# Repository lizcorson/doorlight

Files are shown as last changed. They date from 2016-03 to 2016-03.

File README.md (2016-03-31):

# doorlight
Opening your front door will turn on a strip of LEDs inside. Never walk into a dark house at night! Plus, the strip lights up red so as not to affect your eyes' adjustment to the dark.

## Status
Complete!

## Parts Used
- Pro Mini clone http://www.aliexpress.com/item/Pro-Mini-Module-Atmega328-5V-16M-For-Arduino-Compatible-With-Nano/2021666535.html
- LED strip http://www.aliexpress.com/item/1m-4m-5m-WS2812B-Smart-led-pixel-strip-Black-White-PCB-30-60-144-leds-m/32483042485.html
- Magnetic Door Switch https://www.sparkfun.com/products/13247
- 1000 μF capacitor
- 330 Ω resistor
- DC power jack https://www.sparkfun.com/products/10785
- 5V 2A power supply https://www.sparkfun.com/products/12889
- Circuit board http://smile.amazon.com/gp/product/B00PKVSQX2
- Cast acrylic, 3/16" http://www.mcmaster.com/#8505K82 - in the future, I'd use thinner acrylic.
- Command medium cord clips http://smile.amazon.com/dp/B0084M696A
- Command medium picture hanging strips http://smile.amazon.com/dp/B000M3YGOQ
- 3M mounting tape http://smile.amazon.com/dp/B00004Z4A8

## Build it yourself!

1. Upload the doorlight sketch to your Arduino-compatible board.
2. Solder the circuit shown in the circuit diagram.
3. Make a case. I laser cut mine from acrylic. The laser cutter plans are in the case folder.
4. Attach the command cord clips above your door.
5. Position everything as appropriate for your door and your wiring.
6. Mount the control box case to the wall with command strips.
7. Mount the door sensor to the door. Be sure to put the side with wires on the wall.
8. Slide the LED strip into the command cord clips. Secure the strip to to the clips using mounting tape.
9. Plug everything in, and you're good to go!

## Libraries
FastLED https://github.com/FastLED/FastLED

## Final Build Photos
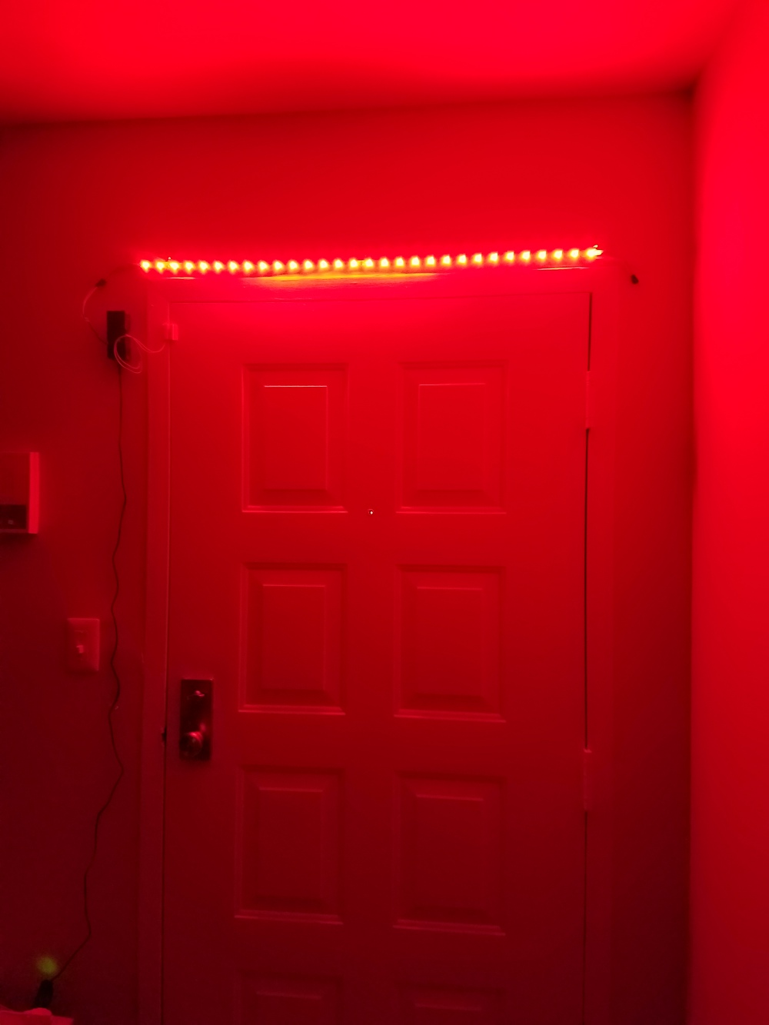
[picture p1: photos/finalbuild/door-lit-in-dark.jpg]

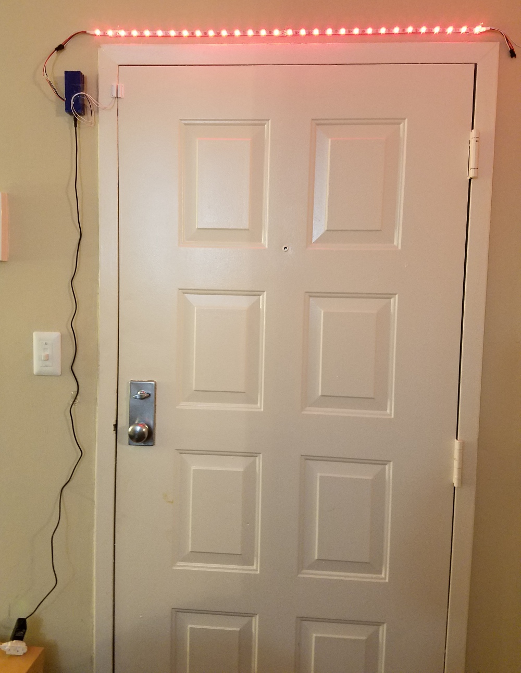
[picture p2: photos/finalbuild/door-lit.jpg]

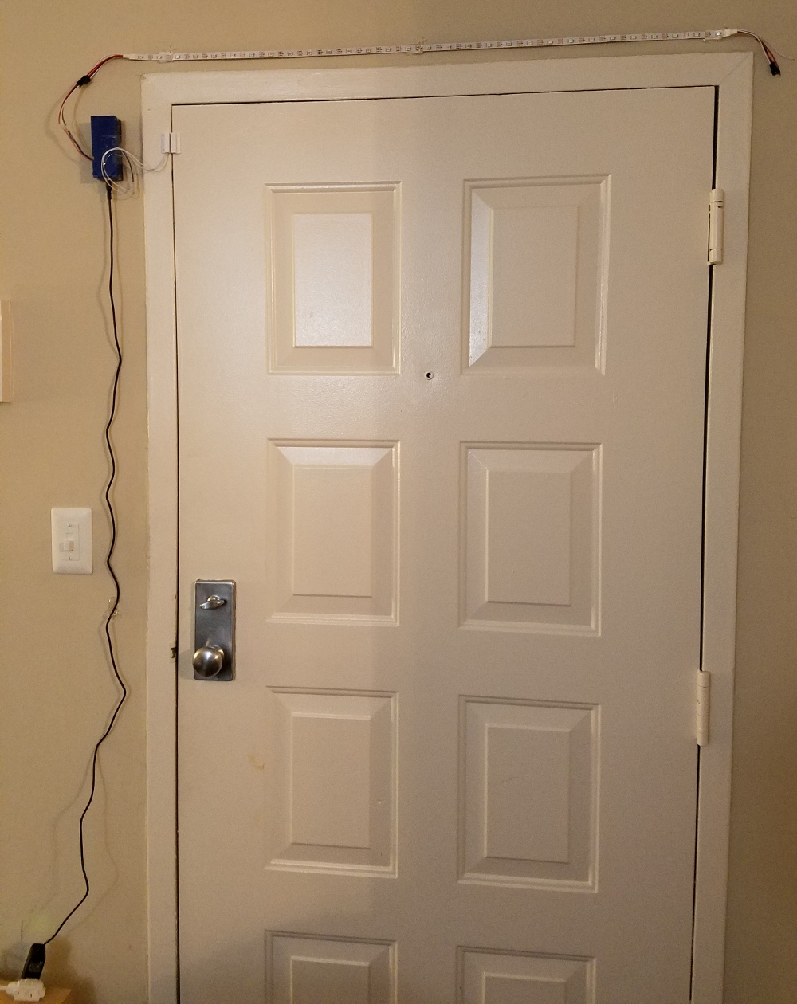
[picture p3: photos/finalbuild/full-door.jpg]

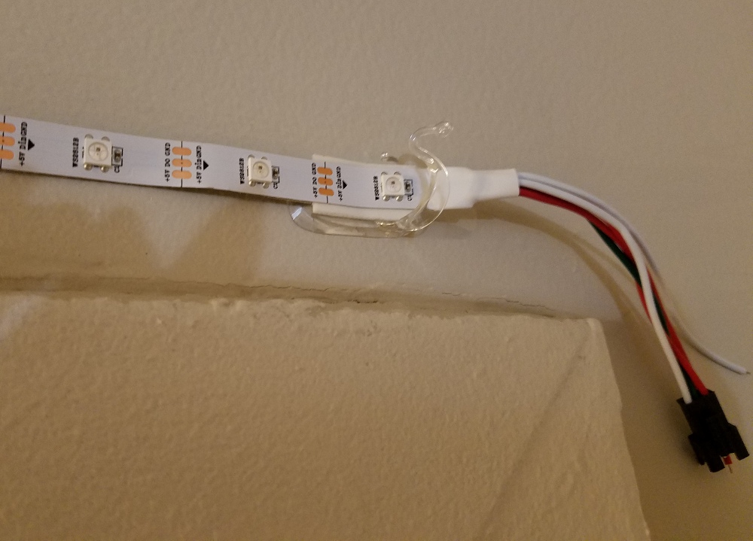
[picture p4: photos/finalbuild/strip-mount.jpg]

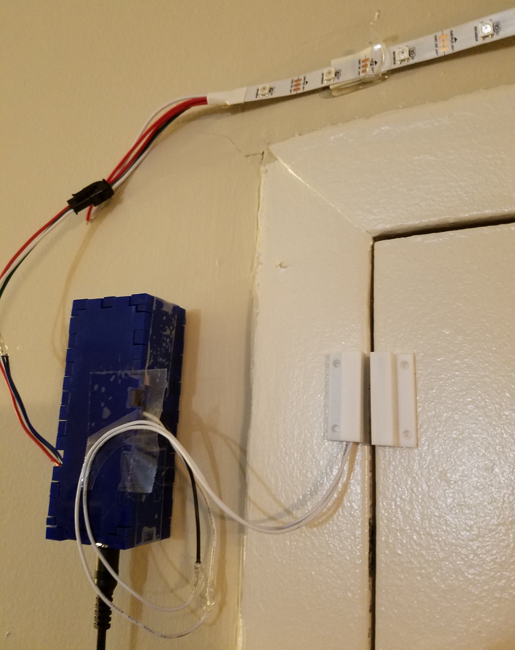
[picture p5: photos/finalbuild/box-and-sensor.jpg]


## Progress Shots
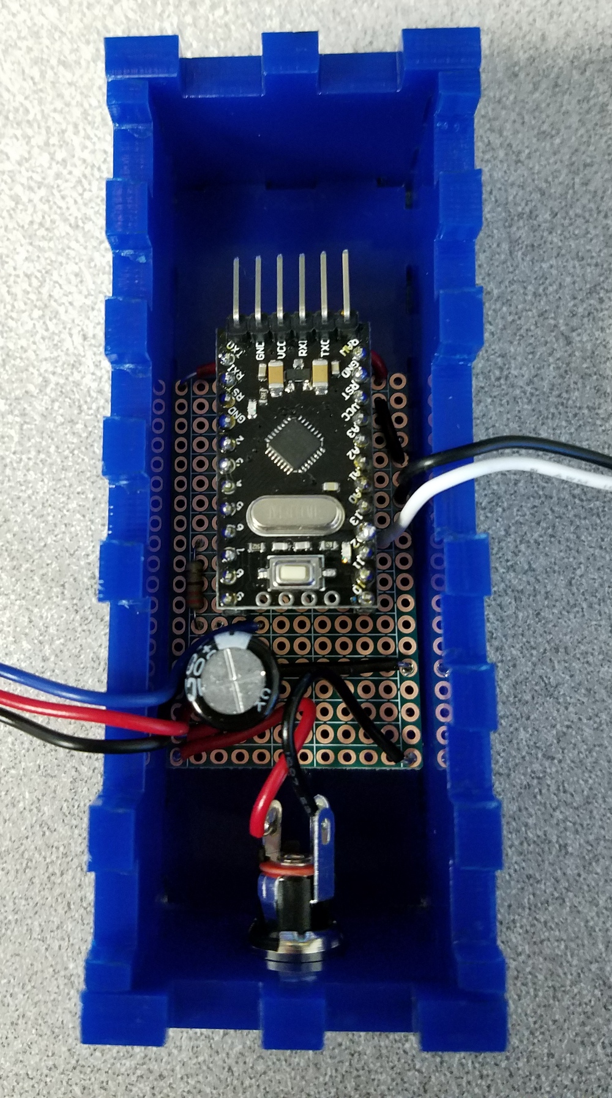
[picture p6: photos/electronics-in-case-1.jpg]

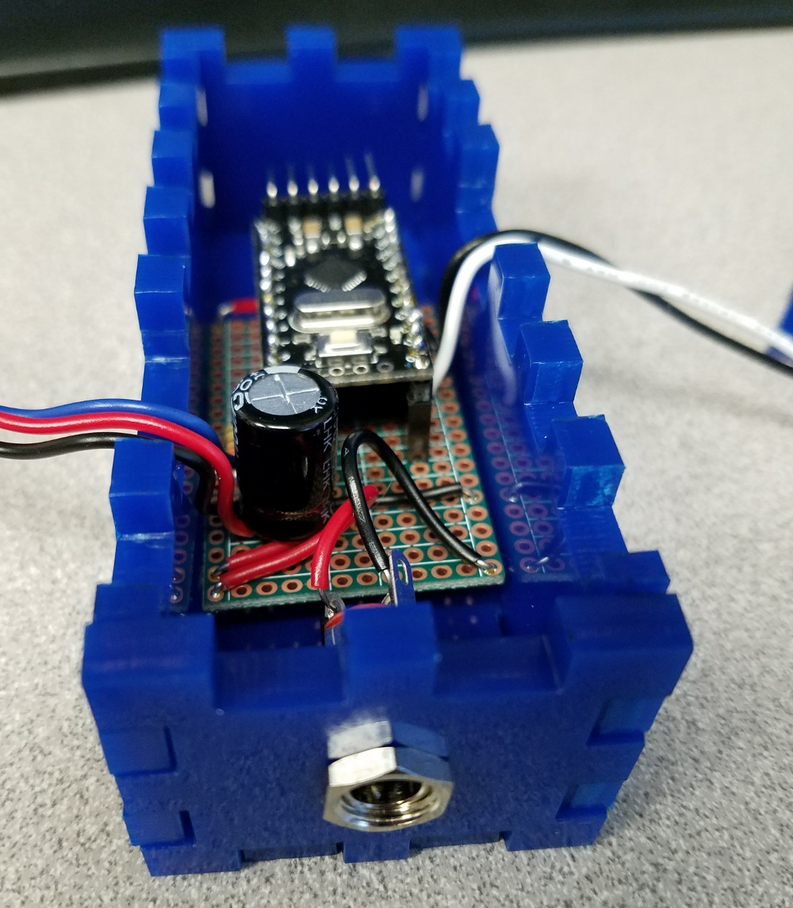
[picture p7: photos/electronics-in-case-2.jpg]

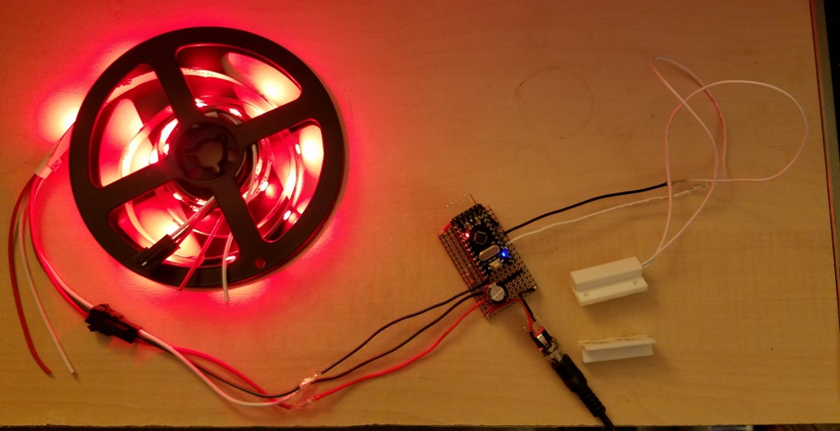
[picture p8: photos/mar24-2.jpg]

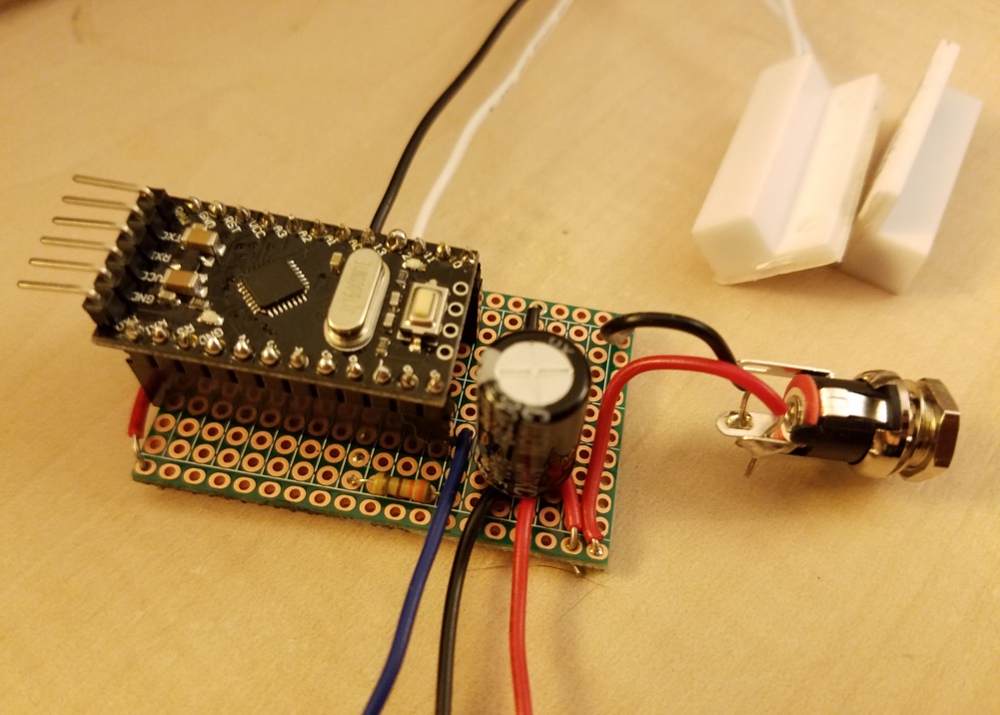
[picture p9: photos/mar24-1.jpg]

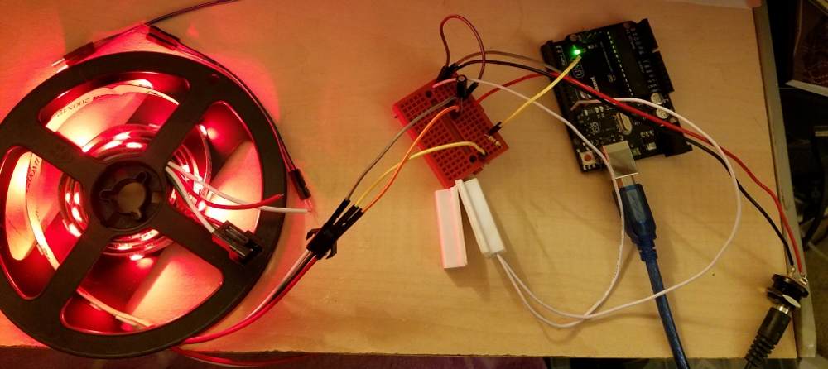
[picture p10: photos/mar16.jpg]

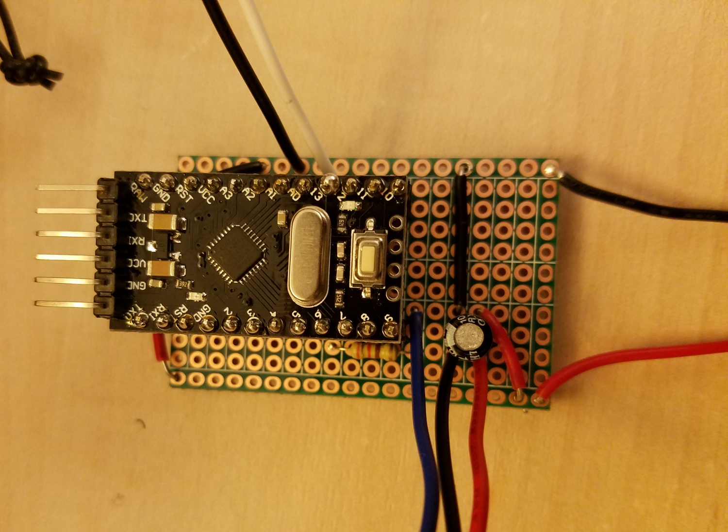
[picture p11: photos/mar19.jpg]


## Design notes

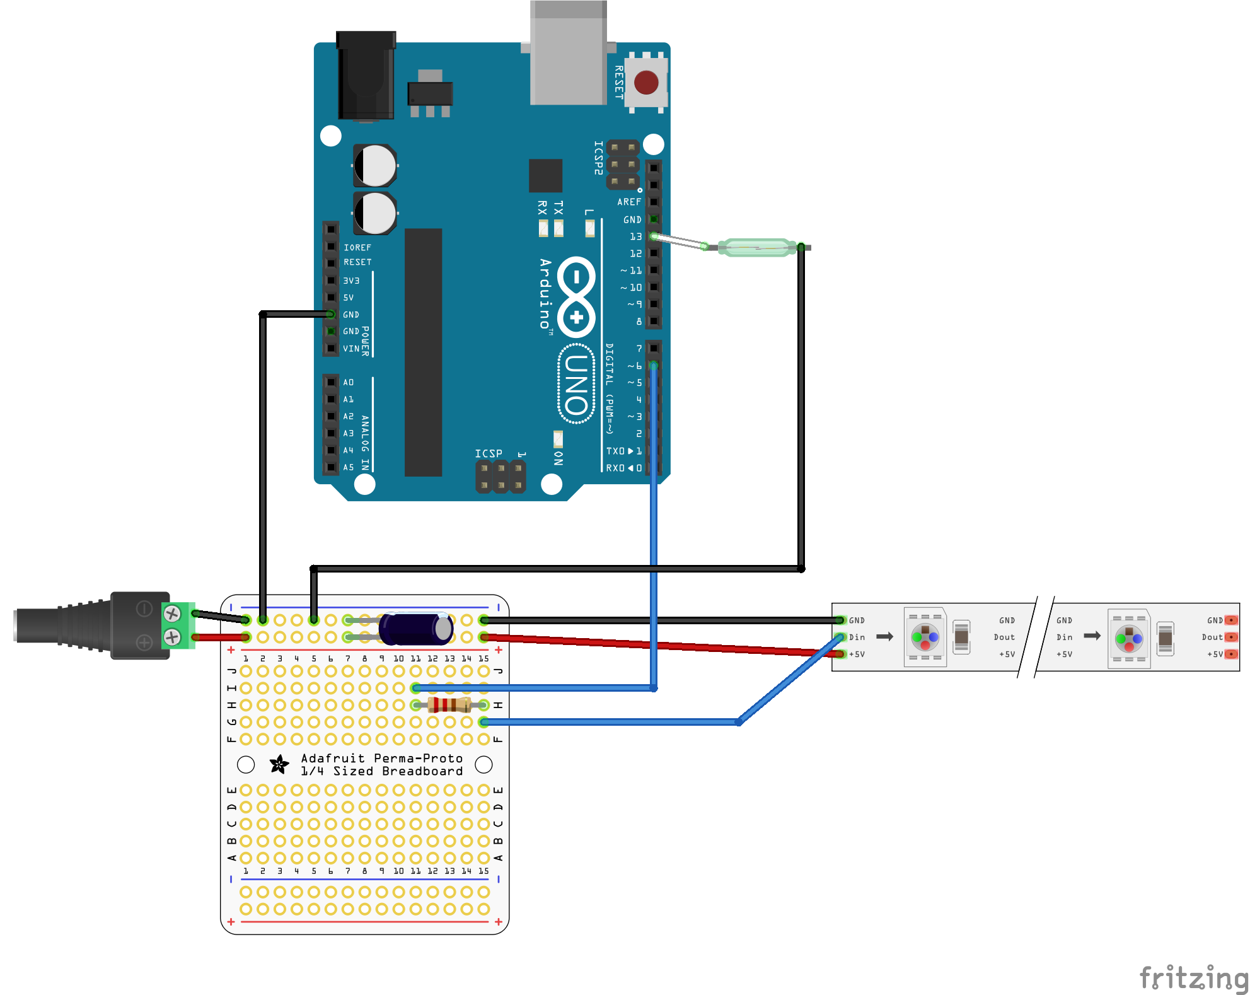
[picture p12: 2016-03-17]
circuitdiagram/doorlight.png

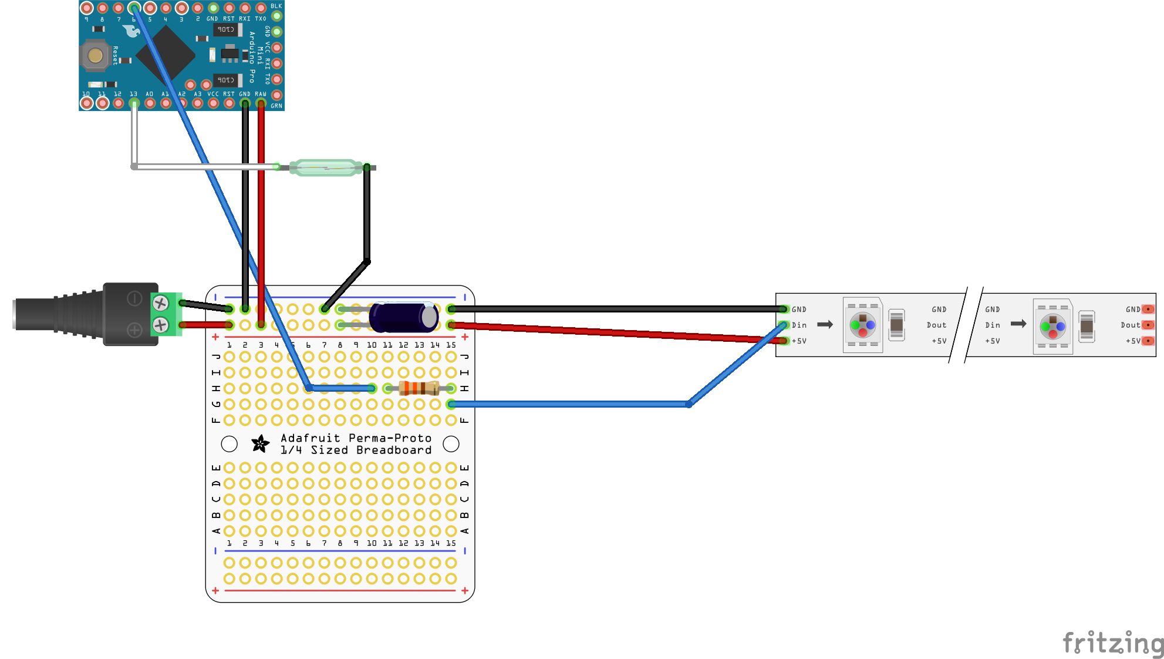
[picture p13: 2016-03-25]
circuitdiagram/doorlight pro mini.png

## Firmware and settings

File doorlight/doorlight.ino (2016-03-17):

/* doorlight
 * Turns an LED strip on when a magnetic door sensor is triggered by a door opening.
 * Turns off after 60 seconds.
 * Thanks to this tutorial: https://learn.adafruit.com/using-ifttt-with-adafruit-io/overview
 * 
 * Liz Corson
 * 16 March 2016
 */

#include "FastLED.h"

#define DOOR 13 // door sensor is on pin 13
#define NUM_LEDS 30
#define DATA_PIN 6 // LED strip on pin 6

const int doorCheckDelay = 500;
long lastDoorCheck = 0;
long lightsOnWait = 60000; //60 seconds
long lightsOnTime = 0;
byte lightsOn = 0;

// Define the array of leds
CRGB leds[NUM_LEDS];

void setup() { 
  	  FastLED.addLeds<NEOPIXEL, DATA_PIN>(leds, NUM_LEDS);
      pinMode(DOOR, INPUT_PULLUP);
      Serial.begin(9600);
      LEDsOff();
}

void loop() { 
  if ((unsigned long)(millis() - lastDoorCheck) > doorCheckDelay) {
    // if door isn't open, we don't need to send anything
    if(digitalRead(DOOR) == LOW) {
      Serial.println("Door closed");
      // we don't do anything
    } else {
      // the door is open if we have reached here,
      // so we should turn LEDs on
      Serial.println("Door is open!");
      if (lightsOn == 0) {
        LEDsOn();
        lightsOn = 1;
        lightsOnTime = millis();
        Serial.println("Lights turned on");
      }
    }
    if (lightsOn == 1) {
        int ontime = (unsigned long)(millis() - lightsOnTime)/1000;
        Serial.print("Lights on for ");
        Serial.print(ontime);
        Serial.println(" s");
      }
    lastDoorCheck = millis();
  }
  
  if ((unsigned long)(millis() - lightsOnTime) > lightsOnWait && lightsOn == 1) {
    lightsOn = 0;
    LEDsOff();
  }
 
}

void LEDsOn() {
    for(int i = 0; i < NUM_LEDS; i++ ){
      leds[i].setRGB(255,0,0);  // setRGB functions works by setting
                             // (RED value 0-255, GREEN value 0-255, BLUE value 0-255)
                             // RED = setRGB(255,0,0)
                             // GREEN = setRGB(0,255,0)
      FastLED.show();
  }
}

void LEDsOff() {
  for(int i = 0; i < NUM_LEDS; i++ ){
    leds[i] = CRGB::Black;
    FastLED.show();
  }
}

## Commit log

2016-03-17 Prototype
    Breadboard prototype is complete and working.
    [doorlight.fzz]
2016-03-19 Pro Mini Version
    Now it's on a circuit board.
    [doorlight pro mini.fzz]
2016-03-25 March 24
    Soldering complete and case plans uploaded.
2016-03-25 March 24a
    Slight circuit diagram/readme correction
    [doorlight pro mini.fzz]
